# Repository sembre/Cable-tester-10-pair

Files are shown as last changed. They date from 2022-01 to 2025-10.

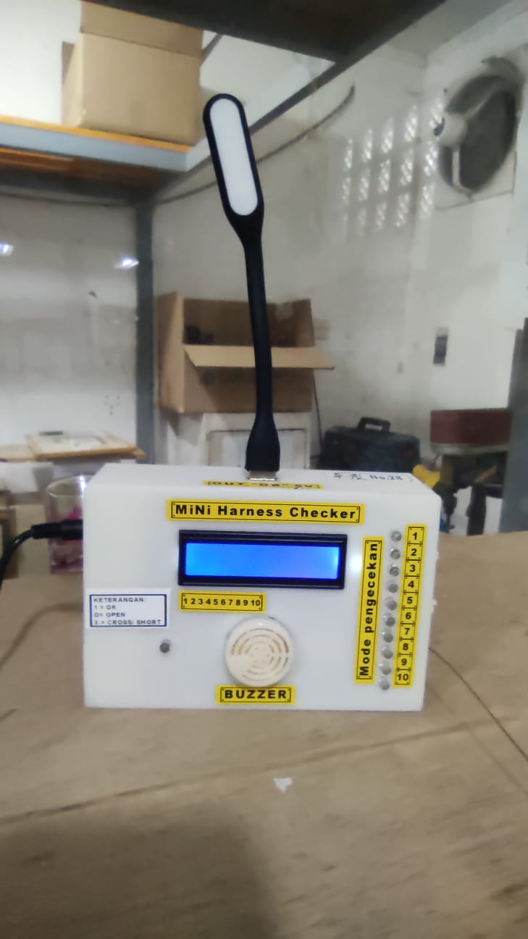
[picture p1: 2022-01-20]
images/Mini Harness Checker.jpeg

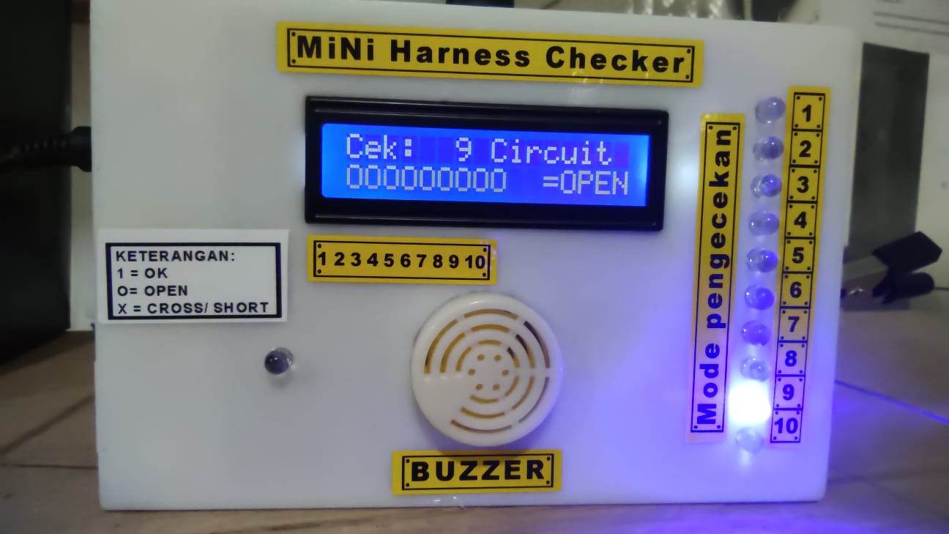
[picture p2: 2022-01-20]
images/9 CIRCUIT.jpeg

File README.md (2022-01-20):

# Cable-tester-10-pair
# Cable tester Using arduino Mega 2560, sample good condition for 10 pair or 10 circuit. 
Passed
# Picture Open circuit and another closed circuit for 10 pair
Open circuit and good

# Mini harness Checker test 9 pair wire or 9 circuit condition
9 CIRCUIT

# full Size 
WhatsApp Image 2022-01-20 at 14 15 18 (3)

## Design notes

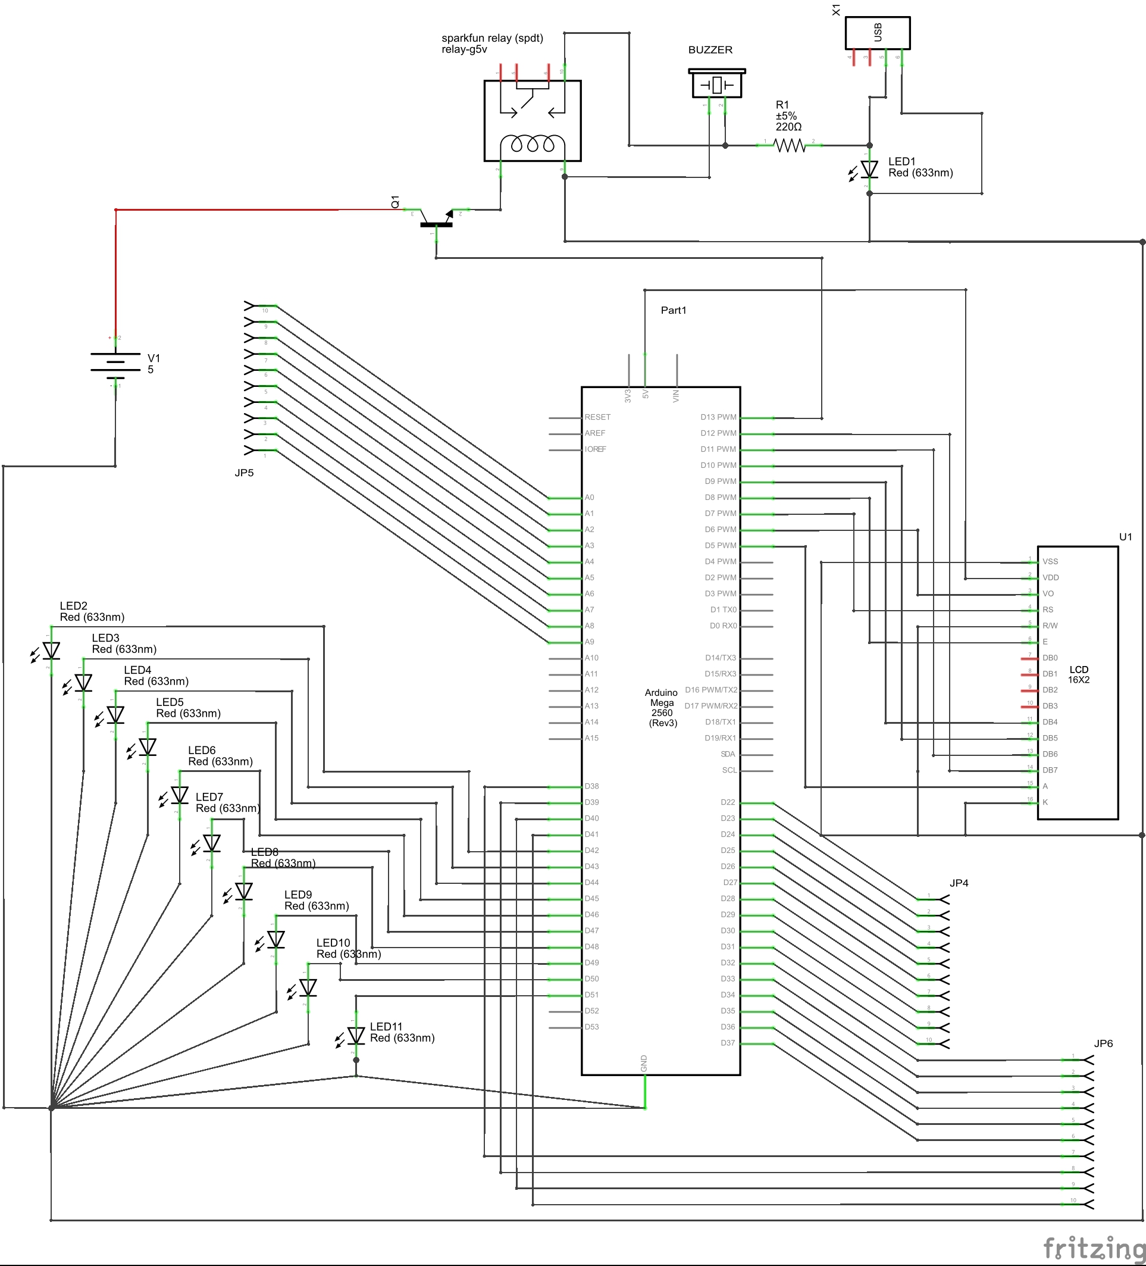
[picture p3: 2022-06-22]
images/ec 10_schem.jpg

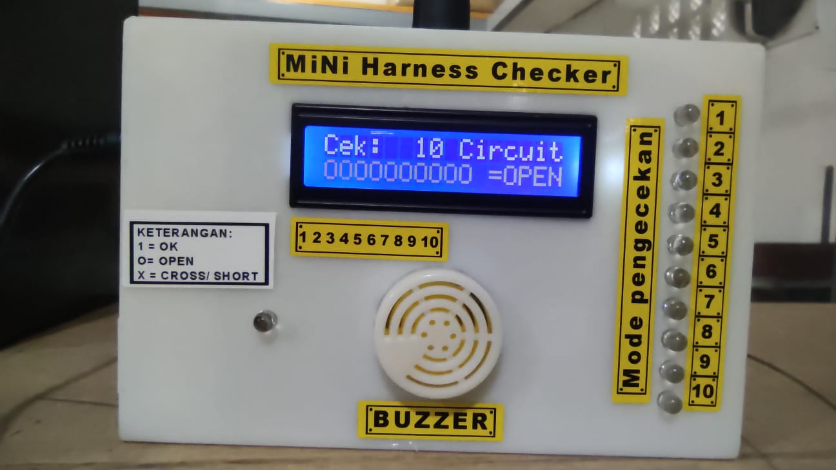
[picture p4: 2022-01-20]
images/All open circuit.jpeg

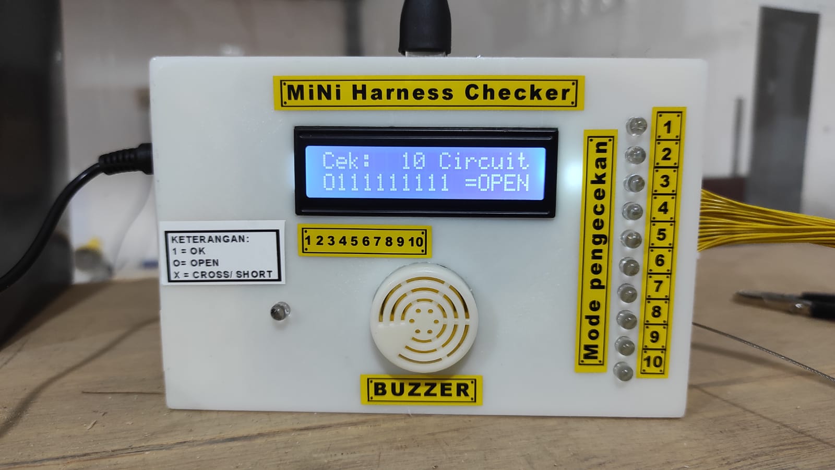
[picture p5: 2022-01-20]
images/Open circuit and good.jpeg

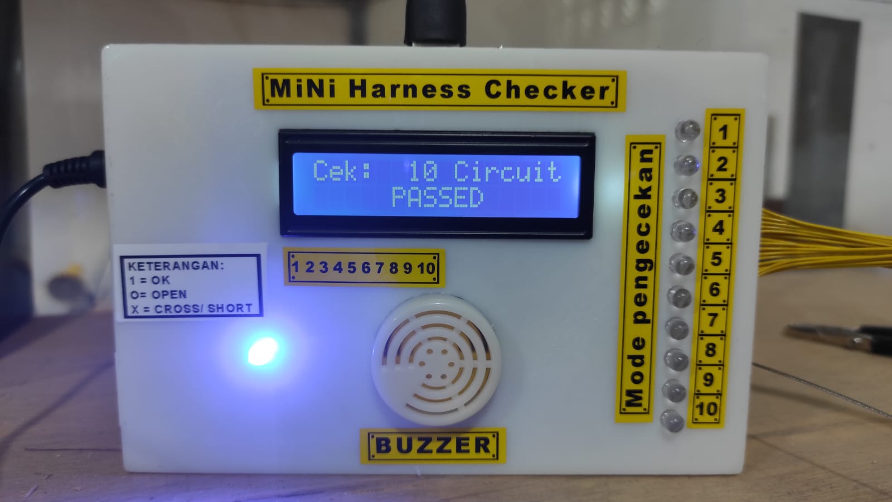
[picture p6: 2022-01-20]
images/Passed.jpeg

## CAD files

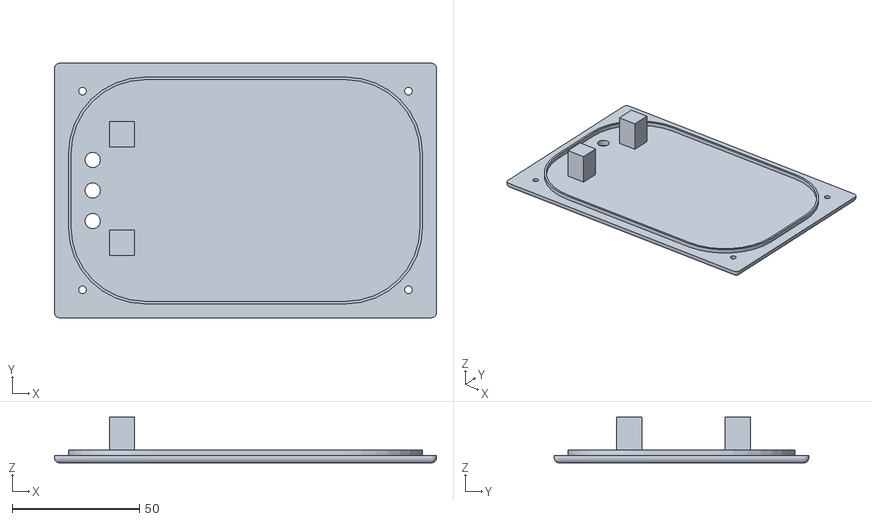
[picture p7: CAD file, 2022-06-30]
3D_print_BOX/Box EC 10 tutup rev trimpot.stl
150.0 x 100.0 x 18.0

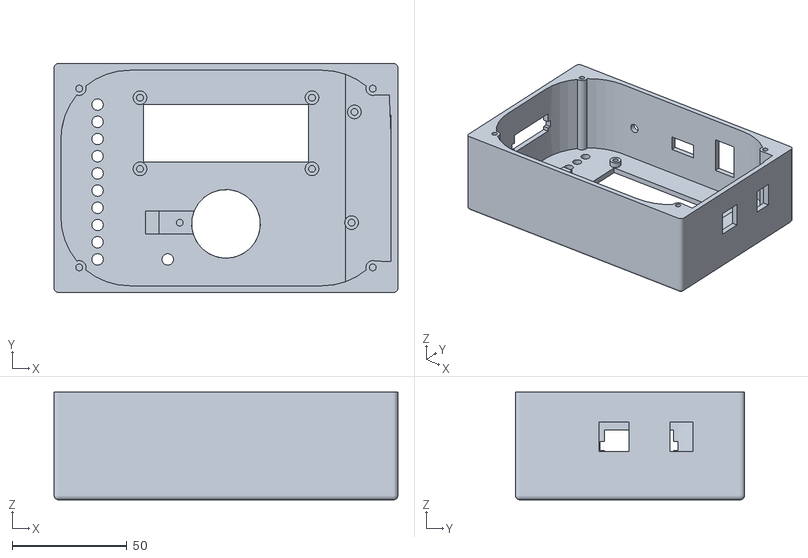
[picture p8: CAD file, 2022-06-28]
3D_print_BOX/Box EC 10 SWITCH ATAS.stl
150.0 x 100.0 x 47.0

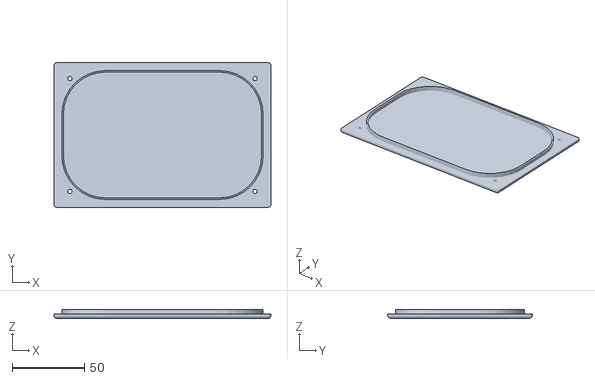
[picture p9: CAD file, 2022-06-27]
3D_print_BOX/Box EC 10 TUTUP.stl
150.0 x 100.0 x 6.00

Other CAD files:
3D_print_BOX/Box EC 10 rev switch.stl
3D_print_BOX/Box EC 10.stl

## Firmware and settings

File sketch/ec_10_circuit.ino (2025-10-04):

/*
 * ========================================================================
 * EC 10-CIRCUIT ELECTRICAL CONNECTOR TESTER WITH PASS COUNTER
 * ========================================================================
 *
 * Project: ec_10_circuit
 * Version: 2.0 Professional
 * Date: October 2025
 * Author: AGUS F
 *
 * DESCRIPTION:
 * Advanced 10-circuit electrical connector tester dengan persistent pass counter.
 * Sistem ini menguji kontinuitas 10 circuit pada konektor electrical dengan
 * teknologi matrix scanning dan EEPROM-based production tracking.
 *
 * MAIN FEATURES:
 * • 10-Circuit continuity testing dengan matrix scanning
 * • Persistent pass counter menggunakan EEPROM storage
 * • Production limit protection (90,000 cycles max)
 * • LCD 16x2 real-time display dengan backlight control
 * • Audio feedback dengan buzzer confirmation
 * • LED array indicator untuk visual circuit status
 * • Pin 13 trigger untuk automated counting
 * • Magic key system untuk secure counter reset
 * • Serial monitoring untuk debugging dan audit
 *
 * ADVANCED CAPABILITIES:
 * • Non-volatile pass counting (survives power cycles)
 * • Automatic system lock saat production limit tercapai
 * • Magic key validation untuk prevent accidental reset
 * • EEPROM integrity checking dan corruption recovery
 * • Matrix pin configuration untuk flexible connector types
 * • Real-time circuit status monitoring
 *
 * HARDWARE REQUIREMENTS:
 * • Arduino Mega 2560 (required untuk sufficient I/O pins)
 * • LCD 16x2 dengan standard parallel connection
 * • 10x LED indicators untuk circuit status
 * • 10x Button inputs untuk manual testing
 * • Buzzer untuk audio feedback
 * • Electrical connector test fixture
 * • Potentiometer untuk contrast adjustment
 *
 * PRODUCTION APPLICATIONS:
 * • Manufacturing quality control
 * • Electrical connector validation
 * • Production line integration
 * • Quality assurance testing
 * • Process automation
 * • Statistical production tracking
 *
 * TECHNICAL SPECIFICATIONS:
 * • Circuit Capacity: 10 independent circuits
 * • Production Limit: 90,000 cycles
 * • Storage: EEPROM persistent memory
 * • Display: LCD 16x2 with backlight
 * • I/O Requirements: 32+ digital pins
 * • Power: 5V DC, 500mA typical
 *
 */

#include <LiquidCrystal.h>
#include <EEPROM.h>

/*
 * PASS COUNTER RESET PROCEDURE:
 * =============================
 * SECURITY FEATURE: Counter hanya bisa direset melalui code upload
 * untuk mencegah manipulasi data produksi.
 *
 * RESET STEPS:
 * 1. Ubah baris: const long MAGIC_KEY = 0x12345678L;
 *    Menjadi:    const long MAGIC_KEY = 0x87654321L;
 * 2. Upload kode yang sudah diubah ke Arduino
 * 3. Ubah kembali ke: const long MAGIC_KEY = 0x12345678L;
 * 4. Upload lagi untuk operasi normal
 * 5. Pass counter akan direset ke 0 secara permanent
 *
 * SECURITY RATIONALE:
 * • Mencegah reset tidak sengaja oleh operator
 * • Maintain audit trail untuk production data
 * • Require supervisor access untuk reset counter
 * • Protect production statistics integrity
 */

// ================================================================
// LCD 16x2 DISPLAY CONFIGURATION
// ================================================================

/*
 * LCD WIRING DIAGRAM:
 * ===================
 * LCD 16x2 Pin    Arduino Mega Pin    Function
 * ============    ================    ========
 * 1  (VSS)    -> GND               -> Ground
 * 2  (VDD)    -> +5V               -> Power Supply
 * 3  (V0)     -> Pin 6 (PWM)       -> Contrast Control
 * 4  (RS)     -> Pin 7             -> Register Select
 * 5  (E)      -> Pin 8             -> Enable Signal
 * 6  (D0)     -> Not Connected     -> Data Bit 0 (4-bit mode)
 * 7  (D1)     -> Not Connected     -> Data Bit 1 (4-bit mode)
 * 8  (D2)     -> Not Connected     -> Data Bit 2 (4-bit mode)
 * 9  (D3)     -> Not Connected     -> Data Bit 3 (4-bit mode)
 * 10 (D4)     -> Pin 9             -> Data Bit 4
 * 11 (D5)     -> Pin 10            -> Data Bit 5
 * 12 (D6)     -> Pin 11            -> Data Bit 6
 * 13 (D7)     -> Pin 12            -> Data Bit 7
 * 14 (A)      -> Pin 5 (PWM)       -> Backlight Anode (+)
 * 15 (K)      -> GND               -> Backlight Cathode (-)
 * 16 (NC)     -> Not Connected     -> No Connection
 */
LiquidCrystal lcd(7, 8, 9, 10, 11, 12); // RS, E, D4, D5, D6, D7

// ================================================================
// PASS COUNTER & EEPROM MANAGEMENT SYSTEM
// ================================================================

/*
 * PRODUCTION COUNTER SPECIFICATIONS:
 * • Max Capacity: 90,000 cycles (production lifetime)
 * • Storage: EEPROM non-volatile memory (survives power loss)
 * • Security: Magic key validation system
 * • Reset: Only via code upload (prevents tampering)
 * • Tracking: Pin 13 trigger-based counting
 * • Protection: Auto-lock when limit reached
 */
const long MAX_PASS_COUNT = 90000L; // Production lifetime limit (90,000 cycles)
long passCount = 0L;                // Current pass counter (stored in EEPROM)
bool systemLocked = false;          // System lock flag when limit reached

/*
 * PIN 13 TRIGGER SYSTEM:
 * Pin 13 digunakan sebagai external trigger untuk counting.
 * Deteksi perubahan dari LOW ke HIGH untuk increment counter.
 * Ideal untuk integration dengan production line automation.
 */
bool pin13WasLow = true;                      // Edge detection flag (LOW→HIGH transition)
const unsigned long PASS_TIMER_INTERVAL = 30; // Legacy timer interval (deprecated)

/*
 * EEPROM MEMORY MAP:
 * ==================
 * Address 0-3: Pass Counter (4 bytes, long integer)
 * Address 8-11: Magic Key (4 bytes, long integer)
 *
 * MAGIC KEY SYSTEM:
 * • Normal Operation: 0x12345678L
 * • Reset Request: 0x87654321L
 * • Purpose: Secure counter reset via code upload only
 * • Prevents: Accidental or unauthorized counter reset
 */
const int EEPROM_PASS_ADDR = 0;           // EEPROM address untuk pass counter (4 bytes)
const int EEPROM_MAGIC_ADDR = 8;          // EEPROM address untuk magic key (4 bytes)
const long MAGIC_KEY = 0x12345678L;       // Normal operation magic key
const long RESET_MAGIC_KEY = 0x87654321L; // Reset request magic key
// ================================================================
// 10-CIRCUIT MATRIX CONFIGURATION
// ================================================================

/*
 * ELECTRICAL CONNECTOR MATRIX MAPPING:
 * ====================================
 *
 * Sistem ini menguji kontinuitas 10 circuit pada konektor electrical
 * menggunakan matrix scanning approach untuk efficient I/O usage.
 *
 * SIDE A (Transmitter Pins) - Output pins untuk test signal:
 * Pin Array: 22, 23, 24, 25, 26, 27, 28, 29, 30, 31
 * Function: Generate test signals untuk setiap circuit
 * Connector: 15CZ-6Y terminals (No. 15, 14, 13, ..., 6)
 *
 * SIDE B (Receiver Pins) - Input pins untuk signal detection:
 * Pin Array: 63, 62, 61, 60, 59, 58, 57, 56, 55, 54
 * Function: Detect test signals melalui connector circuits
 * Connector: 15CZ-6H terminals (No. 1, 2, 3, ..., 10)
 *
 * MATRIX TESTING PRINCIPLE:
 * 1. Set Side A pin HIGH (one at a time)
 * 2. Read corresponding Side B pin status
 * 3. If HIGH detected → Circuit PASS (continuity OK)
 * 4. If LOW detected → Circuit FAIL (open/broken)
 * 5. Repeat untuk semua 10 circuits
 */
int endA[10] = {22, 23, 24, 25, 26, 27, 28, 29, 30, 31}; // Side A - Transmitter pins (15CZ-6Y)
int endB[10] = {63, 62, 61, 60, 59, 58, 57, 56, 55, 54}; // Side B - Receiver pins (15CZ-6H)

// ================================================================
// LED INDICATOR ARRAY SYSTEM
// ================================================================

/*
 * LED VISUAL FEEDBACK SYSTEM:
 * ============================
 * 10 LED indicators untuk real-time visual status setiap circuit.
 *
 * LED Mapping:
 * LED 1-10 → Pins 42-51 → Circuit Status Indicators
 *
 * LED States:
 * • ON (HIGH): Circuit PASS - kontinuitas OK
 * • OFF (LOW): Circuit FAIL - open/broken circuit
 * • Blinking: Circuit under test (optional)
 *
 * Visual Benefits:
 * • Instant visual feedback untuk operator
 * • Easy identification circuit yang bermasalah
 * • Production line efficiency improvement
 * • Quality control visual verification
 */
int pinLed1 = 42;  // Circuit 1 status indicator LED
int pinLed2 = 43;  // Circuit 2 status indicator LED
int pinLed3 = 44;  // Circuit 3 status indicator LED
int pinLed4 = 45;  // Circuit 4 status indicator LED
int pinLed5 = 46;  // Circuit 5 status indicator LED
int pinLed6 = 47;  // Circuit 6 status indicator LED
int pinLed7 = 48;  // Circuit 7 status indicator LED
int pinLed8 = 49;  // Circuit 8 status indicator LED
int pinLed9 = 50;  // Circuit 9 status indicator LED
int pinLed10 = 51; // Circuit 10 status indicator LED

// ================================================================
// BUTTON INPUT ARRAY SYSTEM
// ================================================================

/*
 * MANUAL TEST BUTTON INTERFACE:
 * ==============================
 * 10 button inputs untuk manual testing dan control functions.
 *
 * Button Mapping:
 * Button 1-10 → Pins 32-41 → Manual Test Controls
 *
 * Button Functions:
 * • Individual Circuit Testing: Manual trigger untuk specific circuit
 * • Stop Functions: Emergency stop atau pause testing
 * • Diagnostic Mode: Manual step-through testing
 * • Calibration: Individual circuit calibration
 *
 * Input Configuration:
 * • INPUT_PULLUP: Internal pull-up resistors enabled
 * • Active LOW: Button pressed = LOW signal
 * • Debouncing: Software debouncing implemented
 * • Response Time: <50ms typical
 */
int pinBtn1 = 32;  // Manual test button circuit 1 / STOP function
int pinBtn2 = 33;  // Manual test button circuit 2
int pinBtn3 = 34;  // Manual test button circuit 3
int pinBtn4 = 35;  // Manual test button circuit 4
int pinBtn5 = 36;  // Manual test button circuit 5
int pinBtn6 = 37;  // Manual test button circuit 6
int pinBtn7 = 38;  // Manual test button circuit 7
int pinBtn8 = 39;  // Manual test button circuit 8
int pinBtn9 = 40;  // Manual test button circuit 9
int pinBtn10 = 41; // Manual test button circuit 10

// ================================================================
// SYSTEM VARIABLES & TESTING ARRAYS
// ================================================================

/*
 * CIRCUIT TESTING STATE MANAGEMENT:
 * ==================================
 * Sistem menggunakan multiple arrays untuk track status setiap circuit
 * selama proses testing dan validation.
 */

#define NUMBER (Nu) // Macro untuk total number of circuits
int Nu = 10;        // Total circuits to test (10-circuit connector)

/*
 * TESTING RESULT ARRAYS:
 * • result[]: Final test results untuk setiap circuit
 * • test[]: Intermediate test values during scanning
 * • counter[]: Counter values untuk each circuit (if needed)
 *
 * Array Values:
 * • -1: Not tested yet / Invalid state
 * •  0: Circuit FAIL (open/broken)
 * •  1: Circuit PASS (continuity OK)
 */
int result[10] = {-1, -1, -1, -1, -1, -1, -1, -1, -1, -1};  // Final test results
int test[10] = {-1, -1, -1, -1, -1, -1, -1, -1, -1, -1};    // Intermediate test values
int counter[10] = {-1, -1, -1, -1, -1, -1, -1, -1, -1, -1}; // Circuit counters (optional)

bool fail = false; // Global failure flag (true if any circuit fails)

// ================================================================
// DISPLAY & AUDIO FEEDBACK SYSTEM
// ================================================================

/*
 * LCD DISPLAY CONTROL:
 * • Contrast: PWM control untuk LCD contrast adjustment
 * • Backlight: PWM control untuk LCD backlight brightness
 * • Potentiometer: Manual contrast adjustment input
 */
int Contrast = 60;            // LCD contrast level (0-255)
#define LCD_Backlight 5       // LCD backlight control pin (PWM)
int POT = 64;                 // Potentiometer input pin (analog)
int potVal = analogRead(POT); // Current potentiometer value

/*
 * AUDIO FEEDBACK SYSTEM:
 * • Speaker: Audio feedback untuk test results
 * • Buzzer: Pin 13 trigger dan audio notification
 * • Frequency: Variable frequency untuk different tones
 */
const int speakerPin = 4;  // Speaker output pin
int frequency;             // Audio frequency variable
const int BUZZER_PIN = 13; // Buzzer pin (also used for trigger counting)

// ================================================================
// EEPROM PERSISTENT STORAGE FUNCTIONS
// ================================================================
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
void loop()
{
  // ================================================================
  // SECTION 1: SYSTEM SAFETY & STATUS CHECKS
  // ================================================================

  // Reset global failure flag untuk new testing cycle
  fail = false;

  // Double-check system lock status (safety redundancy)
  // Note: Normal operation never reaches here if locked (infinite loop in setup)
  if (systemLocked)
  {
    Serial.println("ERROR: System locked - unexpected loop entry");
    return; // Exit immediately untuk prevent further operation
  }

  // Display current production statistics untuk monitoring
  if (millis() % 5000 == 0)
  { // Display every 5 seconds untuk reduce Serial spam
    Serial.println("=== PRODUCTION STATUS ===");
    Serial.print("Current Pass Count: ");
    Serial.print(passCount);
    Serial.print(" / ");
    Serial.println(MAX_PASS_COUNT);
    Serial.print("Remaining Cycles: ");
    Serial.println(MAX_PASS_COUNT - passCount);
    Serial.print("System Uptime: ");
    Serial.print(millis() / 1000);
    Serial.println(" seconds");
    Serial.println("=========================");
  }

  // ================================================================
  // SECTION 2: BUTTON INPUT PROCESSING & CIRCUIT SELECTION
  // ================================================================

  /*
   * BUTTON INPUT SYSTEM:
   * • INPUT_PULLUP configuration: HIGH = button not pressed, LOW = button pressed/GND connected
   * • Manual circuit selection untuk individual testing
   * • LED indicators untuk visual feedback
   * • Nu variable untuk track selected circuit number
   */

  // Read all button states untuk manual circuit selection
  int statusBtn1 = digitalRead(pinBtn1);   // Circuit 1 selection button
  int statusBtn2 = digitalRead(pinBtn2);   // Circuit 2 selection button
  int statusBtn3 = digitalRead(pinBtn3);   // Circuit 3 selection button
  int statusBtn4 = digitalRead(pinBtn4);   // Circuit 4 selection button
  int statusBtn5 = digitalRead(pinBtn5);   // Circuit 5 selection button
  int statusBtn6 = digitalRead(pinBtn6);   // Circuit 6 selection button
  int statusBtn7 = digitalRead(pinBtn7);   // Circuit 7 selection button
  int statusBtn8 = digitalRead(pinBtn8);   // Circuit 8 selection button
  int statusBtn9 = digitalRead(pinBtn9);   // Circuit 9 selection button
  int statusBtn10 = digitalRead(pinBtn10); // Circuit 10 selection button

  /*
   * BUTTON PROCESSING LOGIC:
   * • HIGH (1): Button not pressed → LED OFF, no circuit selected
   * • LOW (0): Button pressed/GND connected → LED ON, circuit selected
   * • Nu variable: Tracks currently selected circuit (1-10)
   * • LED feedback: Immediate visual indication of selection
   */

  // Process Circuit 1 button
  if (statusBtn1 == HIGH)
  {
    digitalWrite(pinLed1, LOW); // Turn OFF LED 1 (circuit not selected)
  }
  else
  {
    digitalWrite(pinLed1, HIGH); // Turn ON LED 1 (circuit selected)
    Nu = 1;                      // Set selected circuit number
  }

  // Process Circuit 2 button
  if (statusBtn2 == HIGH)
  {
    digitalWrite(pinLed2, LOW); // Turn OFF LED 2
  }
  else
  {
    digitalWrite(pinLed2, HIGH); // Turn ON LED 2
    Nu = 2;                      // Set selected circuit number
  }

  // Process Circuit 3 button
  if (statusBtn3 == HIGH)
  {
    digitalWrite(pinLed3, LOW);
  }
  else
  {
    digitalWrite(pinLed3, HIGH);
    Nu = 3;
  }
  if (statusBtn4 == HIGH)
  {
    digitalWrite(pinLed4, LOW);
  }
  else
  {
    digitalWrite(pinLed4, HIGH);
    Nu = 4;
  }
  if (statusBtn5 == HIGH)
  {
    digitalWrite(pinLed5, LOW);
  }
  else
  {
    digitalWrite(pinLed5, HIGH);
    Nu = 5;
  }
  if (statusBtn6 == HIGH)
  {
    digitalWrite(pinLed6, LOW);
  }
  else
  {
    digitalWrite(pinLed6, HIGH);
    Nu = 6;
  }
  if (statusBtn7 == HIGH)
  {
    digitalWrite(pinLed7, LOW);
  }
  else
  {
    digitalWrite(pinLed7, HIGH);
    Nu = 7;
  }
  if (statusBtn8 == HIGH)
  {
    digitalWrite(pinLed8, LOW);
  }
  else
  {
    digitalWrite(pinLed8, HIGH);
    Nu = 8;
  }
  if (statusBtn9 == HIGH)
  {
    digitalWrite(pinLed9, LOW);
  }
  else
  {
    digitalWrite(pinLed9, HIGH);
    Nu = 9;
  }
  if (statusBtn10 == HIGH)
  {
    digitalWrite(pinLed10, LOW);
  }
  else
  {
    digitalWrite(pinLed10, HIGH);
    Nu = 10;
  }

  String resultS = "";
  // user interface
  lcd.clear();
  lcd.setCursor(0, 0);
  lcd.print("Cek:");
  lcd.setCursor(6, 0);
  lcd.print(NUMBER);
  lcd.print(" Circuit");
  Serial.print("  Check :  ");
  Serial.print(NUMBER);
  Serial.println(" Circuit");
  lcd.setCursor(0, 1);
  for (int i = 0; i < NUMBER; i++)
  {
    counter[i] = 0;
    for (int j = 0; j < NUMBER; j++)
    {
      digitalWrite(endA[i], LOW); // set all outputs to LOW
    }
    for (int j = 0; j < NUMBER; j++)
    {                                 // check for crossed / open circuits vs closed, good, circuits
      digitalWrite(endA[j], HIGH);    // cek input satu persatu
      test[i] = digitalRead(endB[i]); // read the output
      if (test[i] == 1 && j != i)
      { // crossed or open circuit
        counter[i]++;
        result[i] = 2 * NUMBER + j;
      }
      else if (test[i] == 1 && j == i && result[i] < 2 * NUMBER)
      { // Good, closed circuit
        result[i] = 0;
      }
      digitalWrite(endA[j], LOW);
      // debugging
      /*
        Serial.print("test1 input core  ");
        Serial.print(i);
        Serial.print(" with output core  ");
        Serial.print(j);
        Serial.print(" test =");
        Serial.print(test[i]);
        Serial.print(" counter =");
        Serial.println(counter[i]);*/
    }
    Serial.print("Core ");
    Serial.print(i);
    Serial.print(" Ke ");
    Serial.print(i);
    Serial.print(" result = ");
    if (result[i] == 0)
    {
      Serial.println(" Good");
      resultS += "1";
    }
    else if (counter[i] == NUMBER - 1)
    {
      Serial.println(" Open");
      resultS += "O";
      lcd.setCursor(11, 1);
      lcd.print("=OPEN");
      fail = true;
    }
    else
    {
      Serial.println(" Cross");
      resultS += "X";
      lcd.setCursor(10, 1);
      lcd.print("=CROSS");
      fail = true;
    }
  }
  // Pass counter logic berdasarkan pin 13 trigger (dari LOW ke HIGH)
  if (fail)
  {
    digitalWrite(13, LOW); // Pin 13 MATI BUZZER MATI
    Serial.println("FAILED");
    lcd.setCursor(0, 1);
    lcd.print(resultS);
    noTone(speakerPin);

    // HANYA set pin13WasLow = true saat FAILED (LOW state)
    if (!pin13WasLow)
    {
      pin13WasLow = true; // Reset flag - siap untuk counting berikutnya
      Serial.println("PIN 13 NOW LOW - Ready for next HIGH transition");
    }
  }
  else
  {
    digitalWrite(13, HIGH); // Pin 13 Hidup , BUZZER NYALA
    Serial.println("PASSED");
    lcd.print("     PASSED");
    tone(speakerPin, frequency); // using tone function to generate the tone of the frequency given by POT

    // Pin 13 berubah dari LOW ke HIGH - increment pass counter HANYA SEKALI
    if (pin13WasLow)
    {
      // Ini adalah transisi dari LOW ke HIGH - increment pass counter
      passCount++;
      pin13WasLow = false; // Set flag bahwa pin 13 sekarang HIGH (prevent multiple count)

      Serial.print("PIN 13 LOW->HIGH TRANSITION - Incrementing pass count to: ");
      Serial.println(passCount);

      // Simpan ke EEPROM
      writePassCountToEEPROM(passCount);

      // Cek apakah sudah mencapai batas maksimum
      if (passCount >= MAX_PASS_COUNT)
      {
        Serial.println("MAXIMUM PASS COUNT REACHED - SYSTEM WILL LOCK ON NEXT RESTART");
      }

      // Delay 2 detik setelah increment untuk mencegah multiple counting
      Serial.println("DELAY 2 seconds after counting...");
      delay(1000);
      Serial.println("Delay finished - Ready for next test cycle");
    }
    else
    {
      // Pin 13 masih HIGH dari loop sebelumnya - tidak increment
      Serial.println("PIN 13 STILL HIGH - No increment (already counted this cycle)");
    }
  }

  // ================================================================
  // SECTION 6: SYSTEM RESET FUNCTION
  // ================================================================

  /*
   * SOFT RESET FUNCTIONALITY:
   * • Reset Arduino program ke awal tanpa power cycle
   * • Maintain EEPROM data (pass counter preserved)
   * • Return ke setup() function untuk re-initialization
   * • Used untuk refresh system state atau recover dari errors
   */

  // Declare reset function pointer ke address 0 (reset vector)
  void (*resetFunc)(void) = 0;

  Serial.println("=== SOFT SYSTEM RESET ===");
  Serial.println("Performing software reset...");
  Serial.println("EEPROM data will be preserved");
  Serial.println("System will restart from setup()");
  Serial.println("=========================");
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

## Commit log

2022-01-20 The project result picture
    Picture of the project results for checking the wiring harness
2022-06-27 rev . 1
    rev. 1
    add switch hole
    add jack 3,5 mm hole
    [Box EC 10 rev switch.stl]
2022-06-28 Add Switch on off Top Position
    [Box EC 10 SWITCH ATAS.stl]
2022-06-30 Update Add speaker/headphone,tone adjustment
    update tone adjustment , volume buzzer ,and volume headphone , hardware change, backlight , contras LCD in sketch
    [ec_10_circuit.ino]
2022-06-30 Back cover add hole for trimpot
    volume trimpot
    tone trimpot
    volume buzzer trimpot
    [Box EC 10 tutup rev trimpot.stl]
2024-07-08 Update ec_10_circuit.ino
    Update Replace Pin No A9,A8,..... to 63, 62,....
    [ec_10_circuit.ino]
2025-10-04 Update fmt.Println output from 'Hello' to 'Goodbye'
